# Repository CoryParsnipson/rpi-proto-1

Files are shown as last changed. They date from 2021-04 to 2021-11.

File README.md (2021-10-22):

# rpi-proto-1

This repository contains all (hw, fw, sw) resources for an RPI shell prototype.

# About

The models were made in FreeCAD 0.19. The Assembly4 addon was also installed.

```
OS: Windows 10 Version 2009
Word size of OS: 64-bit
Word size of FreeCAD: 64-bit
Version: 0.19.24276 (Git)
Build type: Release
Branch: releases/FreeCAD-0-19
Hash: a88db11e0a908f6e38f92bfc5187b13ebe470438
Python version: 3.8.6+
Qt version: 5.15.1
Coin version: 4.0.1
OCC version: 7.5.0
Locale: English/United States (en_US)
```

## Functional Blocks

### dpad\_test [Status: failure (do not use)]

This is a small test swatch for metal dome switch PCB trace. This also contains wire holders on the side which (for future reference) work really well for 22 AWG solid core wire.

### dpad\_tactile [Status: success (up to date)]

This is a 3 piece jig for holding OMRON B3F-1000 tactile switches into a dpad configuration. A 2015 new nintendo 3ds XL dpad and silicon mask go on top of the cover and underneath the dpad holder.

### abxy\_tactile [Status: success (up to date)]

This is a 3 piece jig for holding OMRON B3F-1000 tactile switches into an ABXY button cross configuration. This is sized specifically for a 2015+ new Nintendo 3DS XL dpad and silicon mask.

### thumbstick [Status: obsolete]

This is designed to hold a Nintendo Switch thumbstick and (breakout board)[https://www.amazon.com/gp/product/B0191ELDL0/ref=ppx\_yo\_dt\_b\_asin\_title\_o06\_s00?ie=UTF8&psc=1] together.

### thumbstick-v2 [Status: success (up to date)]

This is designed to hold a Nintendo Switch thumbstick and (breakout board)[https://www.amazon.com/gp/product/B0191ELDL0/ref=ppx\_yo\_dt\_b\_asin\_title\_o06\_s00?ie=UTF8&psc=1] together. This version uses two pieces to hold everything in place and requires printing the top piece with supports.

### shoulder-buttons-left-v1 [Status: obsolete]

This contains a 2 piece shoulder button holder along with 2 square shoulder buttons for the left side controller. This design is not very sturdy and it is overly complicated. Not recommended.

### shoulder-buttons-left-v2 [Status: success (up to date)]

This contains a 2 piece shoulder button holder along with 2 square shoulder buttons for the left side controller. This design is sturdier than v1. This does not fit the Nintendo 3DS shoulder buttons.

### controller-chassis-mount-left [Status: success (up to date)]

This is basically thumbstick-v2, dpad\_tactile, and shoulder-buttons-left-v2 fused together into one model. This will have attachments to be fitted onto a chassis and then put inside an outer enclosure. The L1 and L2 shoulder buttons should be printed with the ironing setting enabled for best effect. The select button holder in this is barely functional. This will be improved in the next version.

### controller-chassis-mount-right [Status: success (up to date)]

This is the right controller half, meant to hold a thumbstick, ABXY buttons, and shoulder buttons in place. This isn't a symmetric version of the left controller because the thumbstick only comes in one orientation so the breakout board is mounted vertically instead of horizontally like in the left side. This makes the right controller frame slightly wider than the left side.

### chassis-v1 [Status: obsolete]

This is the main parts to hold everything together. So far only consists of a part that screws into the screen and holds the two controller halves. This model can be used with no problems, but v2 is better.

### chassis-v2 [Status: success (up to date)]

This is a re-make with reinforced sides so the controller hooks bend less. The two protoboard holders has been changed to one protoboard holder and one USB Hub holder. This version also has speaker holders and screw holes for the front enclosure to screw into it.

### enclosure-v1 [Status: WIP]

Contains pieces for the outer case (henceforth referred to as the "enclosure"). Also contains models labeled "test-plate-\*" which are smaller pieces used to prototype fit and features (don't need to print these).

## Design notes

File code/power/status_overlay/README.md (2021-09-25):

Status Overlay
==============

This is a group of scripts that displays an overlay on the desktop with the 
current battery level and other status information (brightness, over-temp,
under/over voltage, etc). This overlay should be able to be hidden or shown
through external input and allow the user to select certain functions like
changing brightness or turning off the system.

Prerequisites
=============

These scripts use Python3. As of the time of this writing, both Python2
and Python3 are pre-installed on Raspbian, but to make Python3 the default,
there is a manual step that must be done.

```
 # manually switch from python2 to python3

 $ sudo rm /usr/bin/python
 $ sudo ln -s /usr/bin/python3 /usr/bin/python
```
 
Install python pip.

```
  $ sudo apt-get install python3-pip
```

Install RPI.GPIO.

```
  $ sudo apt-get install python3-rpi.gpio
```

Install pngview.

```
  $ git clone --depth 1 https://github.com/AndrewFromMelbourne/raspidmx.git
  $ cd raspidmx/
  $ make -j4
  $ sudo cp pngview/pngview /usr/local/bin/
```

Installation
============

```
  $ sudo make install # copy files to /usr/bin and install systemd service to run on boot
  $ sudo make clean   # undo everything that `make install` does

  $ sudo make status  # check on systemd service

  $ sudo make start   # manually start systemd service
  $ sudo make stop    # manually stop systemd service
```

References
==========

[1] https://sourceforge.net/p/raspberry-gpio-python/wiki/Home/ -  RPi.GPIO documentation and examples
[2] https://github.com/d-rez/gbz\_overlay - Reference for making an RPi graphical overlay
[3] https://github.com/torfsen/python-systemd-tutorial - Adding Python script as systemd service

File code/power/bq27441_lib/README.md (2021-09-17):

BQ17441 bash library
====================

This is a small set of functions to let you interface with the BQ27441 fuel
gauge through I2C.

Usage
-----

```
source bq27441 <i2c bus id> <fuel gauge i2c address>
```

e.g.)

```
  #> source bq27441 1 0x55
  #> get_battery_percentage
  #> 27
```

Prerequisites
-------------

```
  sudo apt-get install i2c-tools
  sudo apt-get install bc
```

Block Data Configuration
------------------------

Certain commands require you to put the device into a special "config update"
mode, unseal it, and configure block data access. This is all done with the
`enter_extended_mode` command. Use the corresponding `exit_extended_mode`
command to undo the special device access modes. This is important to
remember for writes especially because they do not get finalized back to
storage until the exit command is issued and the device has gone through
soft reset.

E.g.)

```
  source bq27441_lib.sh 1 0x55

  enter_extended_mode # will print to stderr and return non-zero status if fails
  
  read_block_data 0x52 0x0A 2
  # etc

  exit_extended_mode
```

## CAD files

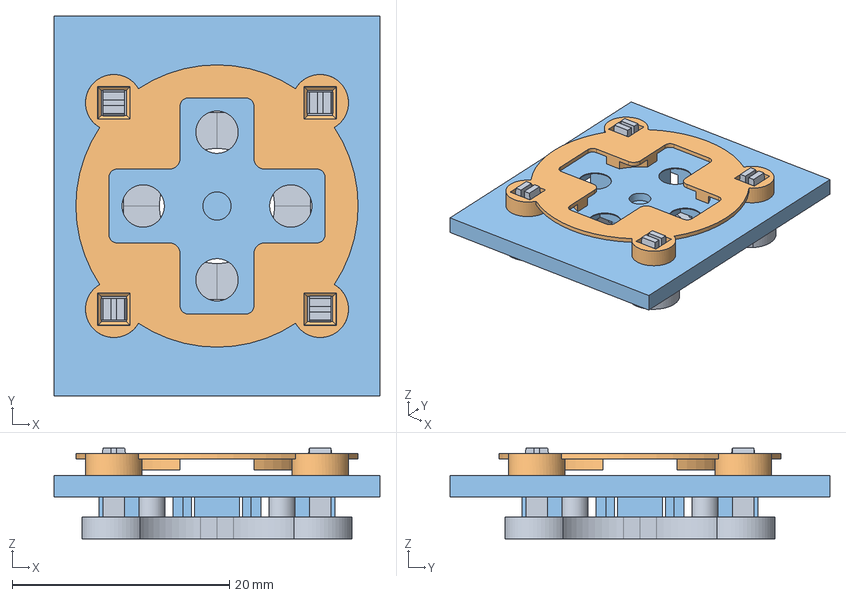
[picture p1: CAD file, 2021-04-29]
models/dpad_tactile/dpad_tactile_asm.FCStd
30.0 x 35.0 x 8.35 mm

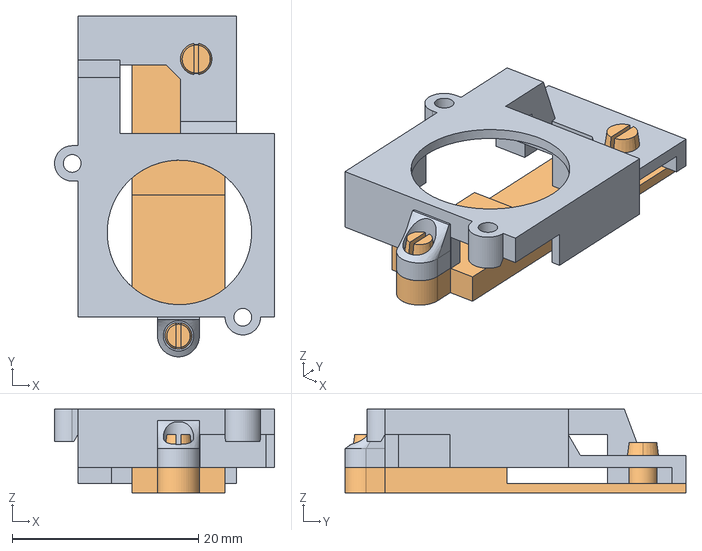
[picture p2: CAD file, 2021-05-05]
models/thumbstick-v2/thumbstick-asm.FCStd
23.6 x 36.5 x 9.00 mm

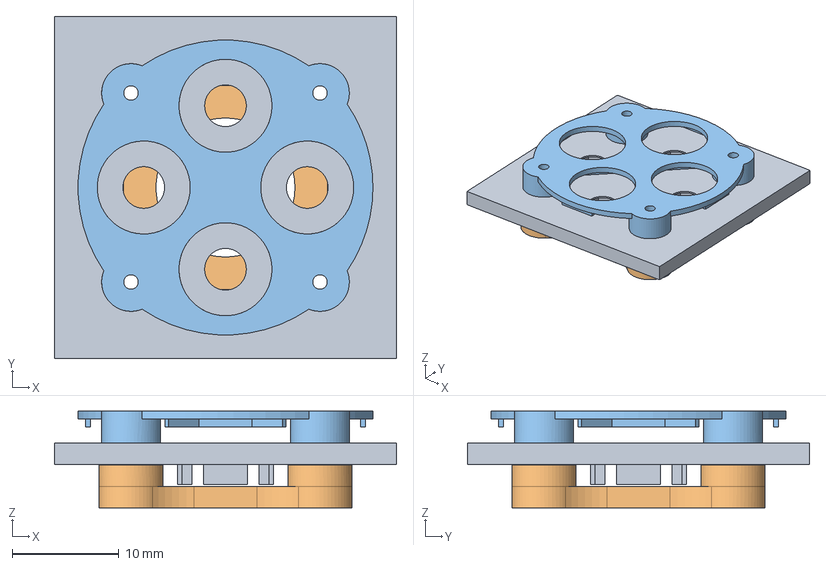
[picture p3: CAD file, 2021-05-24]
models/abxy_tactile/abxy-tactile-asm.FCStd
32.0 x 32.0 x 9.05 mm

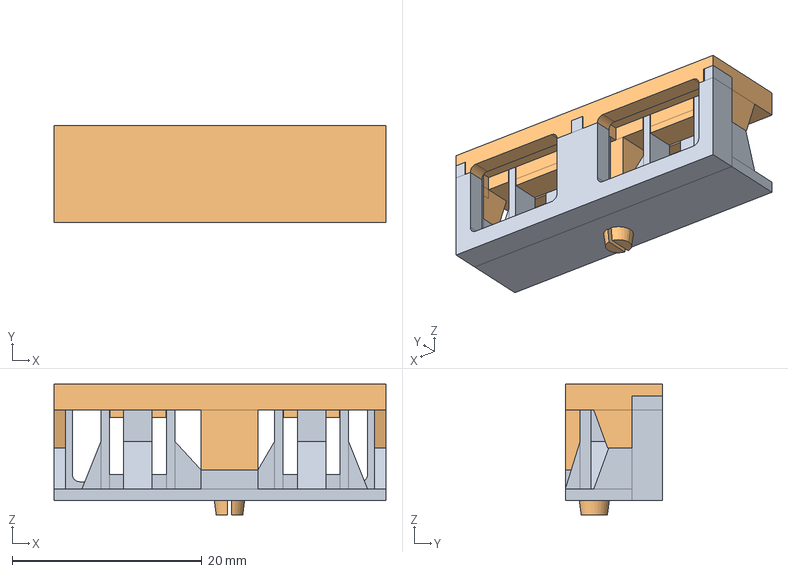
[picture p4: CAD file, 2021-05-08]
models/shoulder-buttons-left-v2/shoulder-buttons-asm.FCStd
35.0 x 10.2 x 13.8 mm

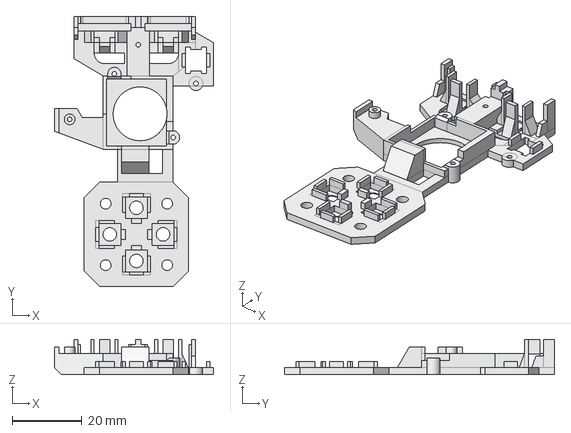
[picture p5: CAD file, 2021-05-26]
controller-chassis-mount-right/top-plate.FCStd
45.7 x 77.7 x 10.2 mm

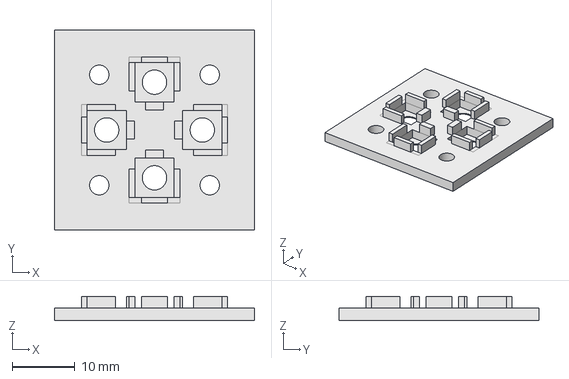
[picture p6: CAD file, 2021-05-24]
models/abxy_tactile/abxy-cover.FCStd
32.0 x 32.0 x 3.85 mm

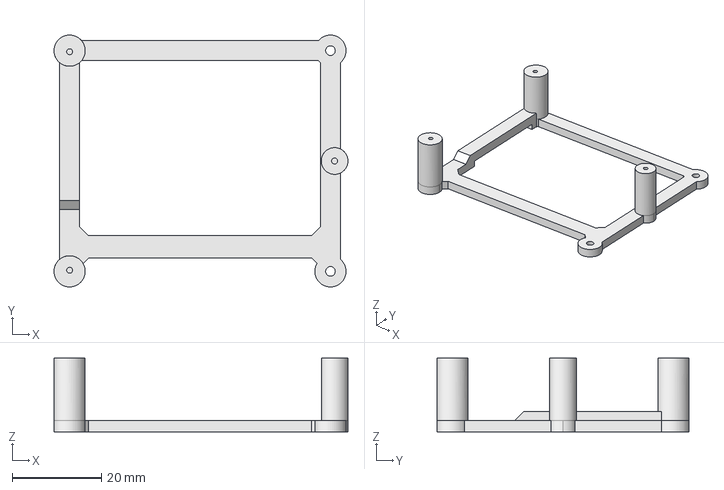
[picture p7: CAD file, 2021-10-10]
models/chassis-v2/rpi-mounting-bracket.FCStd
65.9 x 56.5 x 16.5 mm

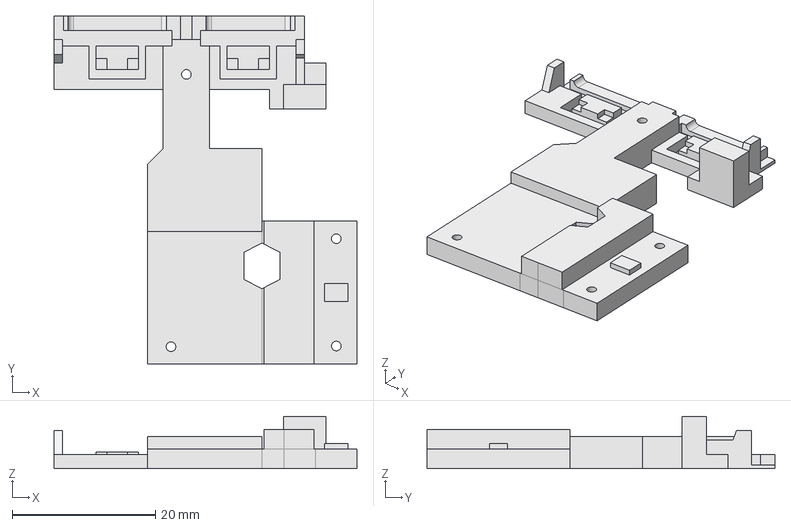
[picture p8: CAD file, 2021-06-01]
models/controller-chassis-mount-left/bottom-plate.FCStd
42.3 x 48.6 x 7.30 mm

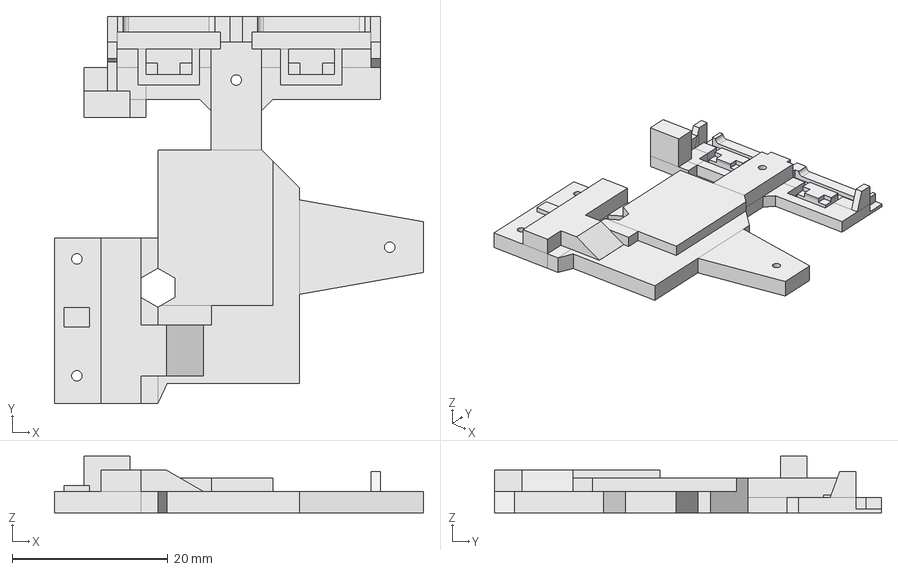
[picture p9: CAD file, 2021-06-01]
models/controller-chassis-mount-right/bottom-plate.FCStd
47.4 x 49.7 x 7.30 mm

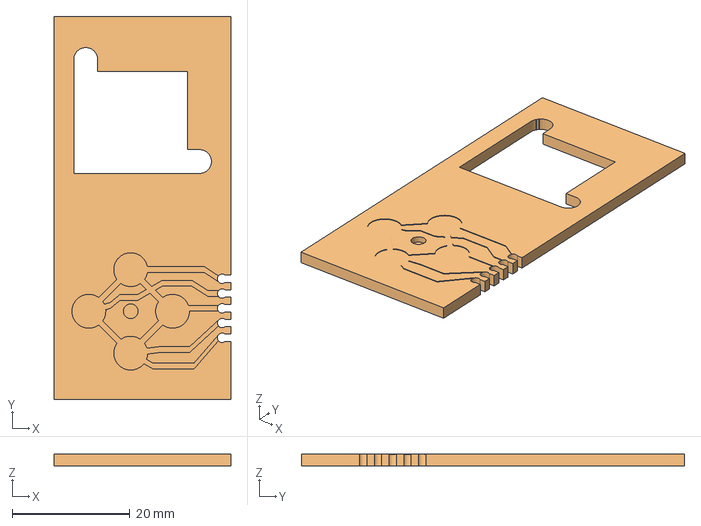
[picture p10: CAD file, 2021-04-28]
models/dpad_test/dpad_test.FCStd
30.0 x 65.0 x 2.00 mm
Pocket012 (Meshed)

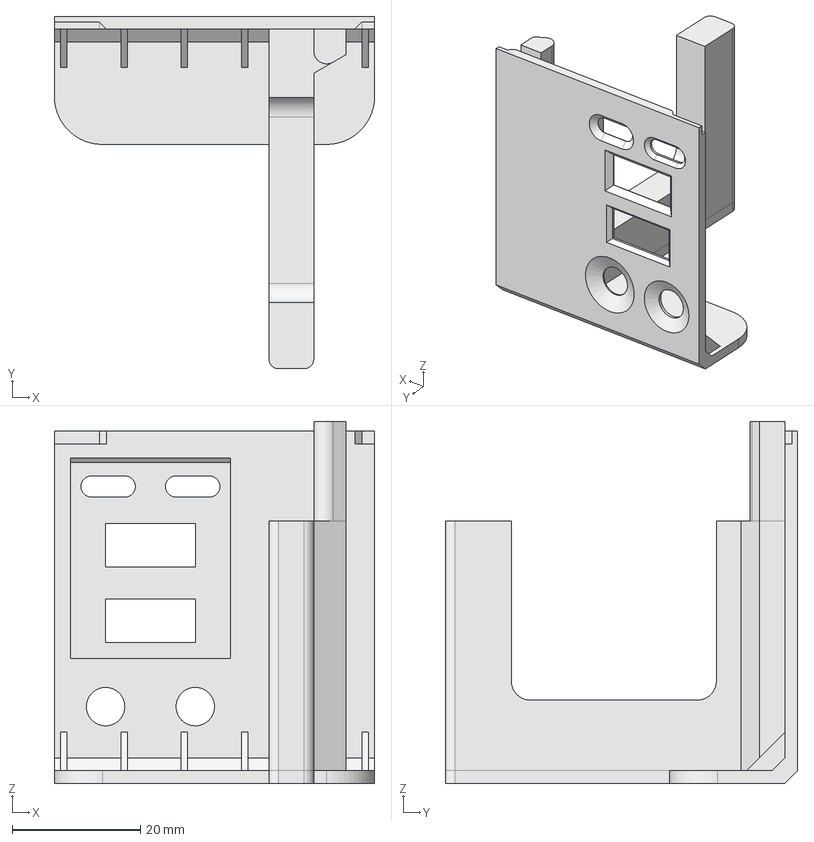
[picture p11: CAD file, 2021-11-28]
models/enclosure-v1/test-plate-chamfer-brace.FCStd
50.0 x 55.0 x 56.5 mm

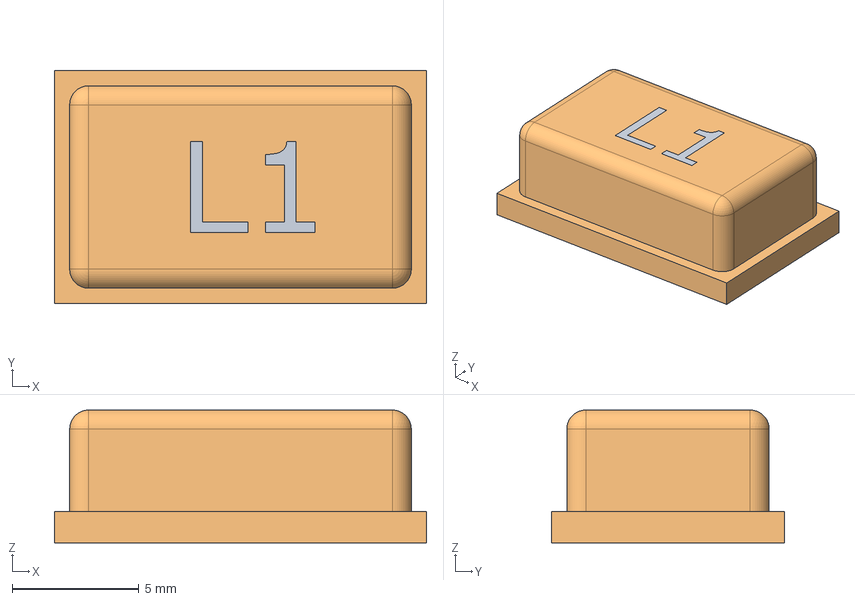
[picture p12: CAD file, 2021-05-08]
models/shoulder-buttons-left-v2/L1-button.FCStd
14.7 x 9.20 x 5.25 mm

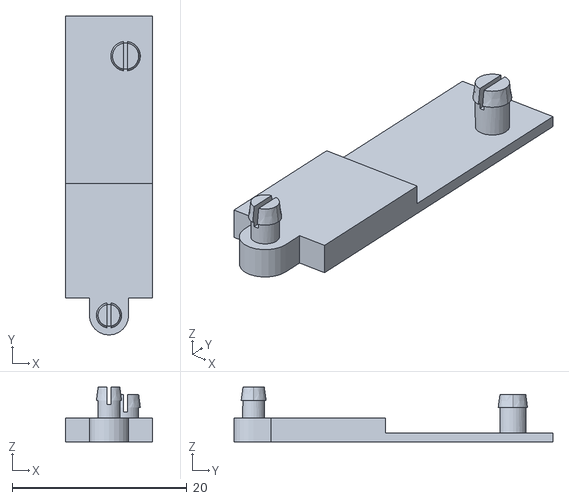
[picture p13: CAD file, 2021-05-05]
models/thumbstick-v2/thumbstick-holder-v2-bottom.stl
10.0 x 36.5 x 6.25

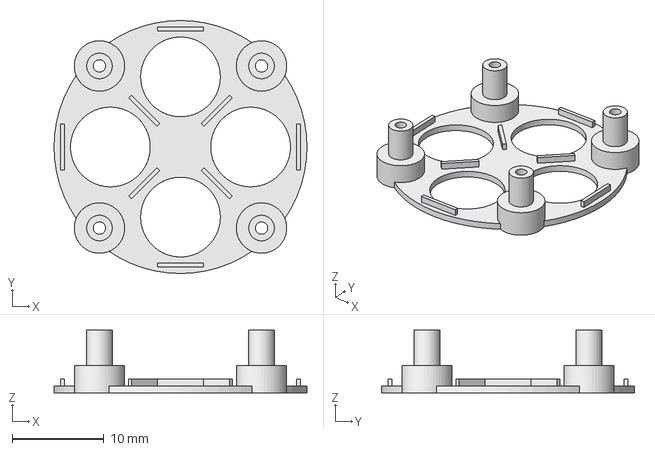
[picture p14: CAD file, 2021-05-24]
models/abxy_tactile/button-holder.FCStd
27.6 x 27.6 x 6.85 mm

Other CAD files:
models/chassis-v2/charger-mounting-bracket.FCStd
models/controller-chassis-mount-left/dpad_undercarriage.FCStd
models/controller-chassis-mount-right/prusa_mk3_settings.3mf
models/dpad_tactile/dpad_tactile_cover.FCStd
models/abxy_tactile/abxy-cover.stl
models/abxy_tactile/button-holder.stl
models/chassis-v1/screen-backing.FCStd
models/chassis-v1/screen-backing.stl
models/chassis-v2/charger-mounting-bracket.stl
models/chassis-v2/power-switch-holder.FCStd
models/chassis-v2/power-switch-holder.stl
models/chassis-v2/rpi-mounting-bracket.stl
models/chassis-v2/screen-backing.FCStd
models/chassis-v2/screen-backing.stl
models/chassis-v2/second-tier-holder-v2.FCStd
models/chassis-v2/second-tier-holder-v2.stl
models/chassis-v2/second-tier-holder.FCStd
models/chassis-v2/second-tier-holder.stl
models/controller-chassis-mount-left/L1-button.FCStd
models/controller-chassis-mount-left/L2-button.FCStd
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

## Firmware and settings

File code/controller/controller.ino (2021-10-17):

#include <HID-Project.h>
#include <HID-Settings.h>

#define MSG_LEN 80

#undef ENABLE_SERIAL // change to #define ENABLE_SERIAL if you want serial turned on

#ifdef ENABLE_SERIAL
  #define PRINT_SERIAL(...) \
    snprintf(msg, MSG_LEN - 1, __VA_ARGS__); /* snprintf to avoid accidental buffer overflow */ \
    Serial.println(msg);
#else
  #define PRINT_SERIAL(...) \
    do {} while(0)
#endif

#ifdef ENABLE_SERIAL
  #define INIT_SERIAL(baudRate) \
    Serial.begin(baudRate); \
    while (!Serial) { \
      ; /* wait for serial port to connect. Needed for native USB */ \
    } \
    PRINT_SERIAL("Serial monitor enabled")
#else
  #define INIT_SERIAL(baudRate) \
    do {} while(0)
#endif

const int refreshInterval = 1000;

char* msg = new char[MSG_LEN];

const int numRows = 4;
const int numCols = 4;

const int rowPins[numRows] = { 7, 8, 10, 16 };
const int colPins[numCols] = { 3, 4, 14, 15 };

const int leftThumbstickButtonPin = 9;
const int rightThumbstickButtonPin = 2;

// These calibrated values are different per individual thumbstick and need to be obtained
// by reading the value of the analog pins, bringing the thumbstick to the max/min of each axis
// and then using a number that is ~10 smaller/larger than what is observed.
const int rXMinCalibrated = 85;
const int rXMaxCalibrated = 850;
const int rYMinCalibrated = 160;
const int rYMaxCalibrated = 840;

const int lXMinCalibrated = 170;
const int lXMaxCalibrated = 890;
const int lYMinCalibrated = 100;
const int lYMaxCalibrated = 840;

const int pinLXAxis = A0;
const int pinLYAxis = A1;
const int pinRXAxis = A3;
const int pinRYAxis = A2;

void reset();
inline void printAnalog(const int16_t xval, const int16_t yval);
int16_t readAxis(int pin, const int min, const int max, boolean returnRaw = false);

void setup() {
  digitalWrite(pinLXAxis, LOW);
  digitalWrite(pinLYAxis, LOW);
  digitalWrite(pinRXAxis, LOW);
  digitalWrite(pinRYAxis, LOW);

  // thumbstick buttons are not part of key matrix
  pinMode(leftThumbstickButtonPin, INPUT_PULLUP);
  pinMode(rightThumbstickButtonPin, INPUT_PULLUP);
    
  reset();

  INIT_SERIAL(115200);

  Gamepad.begin();
}

void loop() {
  static unsigned long now = 0, nextUpdate = 0;
  now = micros();

  if (nextUpdate < now) {
    // TODO: maybe sleep would let us squeeze out extra battery life here
    nextUpdate = now + refreshInterval; 

    for (int c = 0; c < numCols; ++c) {
      byte col = colPins[c];
      pinMode(col, OUTPUT);
      digitalWrite(col, LOW);
  
      for (int r = 0; r < numRows; ++r) {
        byte row = rowPins[r];
        byte current_button = c * numCols + r + 1;

        pinMode(row, INPUT_PULLUP);
        bool button_state = !digitalRead(row);
        pinMode(row, INPUT); // set pin to hi-z
  
        if (button_state) {
          Gamepad.press(current_button);
          PRINT_SERIAL("Row %i, Col %i detected", row, col);
        } else {
          Gamepad.release(current_button);
        }
      }
      pinMode(col, INPUT);
    }

    // left thumbstick button polling
    if (!digitalRead(leftThumbstickButtonPin)) {
      Gamepad.press(numRows * numCols + 1);
    } else {
      Gamepad.release(numRows * numCols + 1);
    }

    // right thumbstick button polling
    if (!digitalRead(rightThumbstickButtonPin)) {
      Gamepad.press(numRows * numCols + 2);
    } else {
      Gamepad.release(numRows * numCols + 2);
    } 

    Gamepad.xAxis(readAxis(pinLXAxis, lXMinCalibrated, lXMaxCalibrated));
    Gamepad.yAxis(-1 * readAxis(pinLYAxis, lYMinCalibrated, lYMaxCalibrated)); // invert y axis
    
    Gamepad.rxAxis(readAxis(pinRXAxis, rXMinCalibrated, rXMaxCalibrated));
    Gamepad.ryAxis(-1 * readAxis(pinRYAxis, rYMinCalibrated, rYMaxCalibrated)); // invert y axis

    Gamepad.write();
  }
}

void reset() {
  for (int r = 0; r < numRows; ++r) {
    pinMode(rowPins[r], INPUT);
  }
  
  for (int c = 0; c < numCols; ++c) {
    pinMode(colPins[c], INPUT_PULLUP);
  }
}

void printAnalog(int16_t xval, int16_t yval) {
  PRINT_SERIAL("x-axis: %d, y-axis: %d", xval, yval);
}

int16_t readAxis(int pin, const int min, const int max, bool returnRaw) {
  uint16_t read = analogRead(pin);
  if (returnRaw) {
    return read;
  }

  return map(constrain(read, min, max), min, max, -32767, 32767);
}

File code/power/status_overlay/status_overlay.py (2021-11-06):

#!/usr/bin/env python3

import datetime
import imghdr
import json
import os
import re
import signal
import struct
import subprocess
import sys
import threading
import time

import RPi.GPIO as GPIO


CONFIG = {}

CONFIG["CONFIG_FILE_PATH"] = "~/.status_overlay_config"

CONFIG["IMAGE_PATH"] = "images/"
CONFIG["SOUND_PATH"] = "sounds/"
CONFIG["LIB_PATH"] = "lib/"
CONFIG["PNGVIEW_PATH"] = "pngview"
CONFIG["SCREENSHOT_PATH"] = "~/screenshots"

CONFIG["LAYER_DEFAULT"] = 15000
CONFIG["LAYER_BATTERY"] = CONFIG["LAYER_DEFAULT"] + 5
CONFIG["LAYER_NUMBER"] = CONFIG["LAYER_DEFAULT"] + 10
CONFIG["LAYER_BACKDROP"] = CONFIG["LAYER_DEFAULT"] - 10
CONFIG["LAYER_NOTIFICATION"] = CONFIG["LAYER_DEFAULT"] + 15

CONFIG["DISPLAY_ID"] = 0
CONFIG["IS_VISIBLE"] = True

# INITIAL_ON -> toggle mode, start with hud visible
# INITIAL_OFF -> toggle mode, start with hud hidden
# SAVED -> toggle mode, start with state read from config file
# FLASH (show hud on button press for a short time then hide)
# FLASH_INITIAL_ON -> Flash mode with hud shown for 3 seconds on start
CONFIG["POWER_SWITCH_BEHAVIOR"] = "SAVED"

CONFIG["POWER_SWITCH_FLASH_DURATION"] = 3 # in seconds

CONFIG["FUEL_GAUGE_SCRIPT_PATH"] = CONFIG["LIB_PATH"] + "bq27441_lib/"
CONFIG["FUEL_GAUGE_I2C_BUS_ID"] = 1
CONFIG["FUEL_GAUGE_I2C_DEVICE_ID"] = 0x55

CONFIG["BATTERY_GPOUT_PIN"] = 29 # board pin 29 is GPIO5
CONFIG["BATTERY_POWER_PIN"] = 36 # board pin 36 is GPIO16 (tied to GPIO6 in hardware)

CONFIG["LOW_BATTERY_NOTIFICATION_DURATION"] = 5 # in seconds
CONFIG["CRITICAL_BATTERY_NOTIFICATION_DURATION"] = 10 # in seconds
CONFIG["LOW_BATTERY_THRESHOLD"] = 10
CONFIG["CRITICAL_BATTERY_THRESHOLD"] = 5


__ORIGINAL_SIGINT__ = None
__LAST_POWER_BUTTON_PRESSED_TIME__ = None
__PNGVIEW_PROCESSES__ = {}
__NOTIFICATION_PROCESSES__ = {}
__DIMENSION_CACHE__ = {}
__PREVIOUS_STATE_OF_CHARGE__ = 100
__SHUTDOWN_LOCK__ = threading.Lock()
__SCRIPT_PATH__ = os.path.dirname(os.path.realpath(__file__))


# -----------------------------------------------------------------------------
# Configuration utilities
# -----------------------------------------------------------------------------
def read_config_file(config_file_path):
    """ Read the config file, if it exists and update the necessary
        configuration parameters and return a dictionary with the
        configuration parameters.

        NOTE: this does not overwrite the configuration, the caller
        must do this themselves.
    """
    config_file_path = os.path.expanduser(config_file_path)
    config = CONFIG

    try:
        with open(config_file_path, 'r') as fhandle:
            serialized = ' '.join(fhandle.readlines())
            config = json.loads(serialized)
    except FileNotFoundError as e:
        print("WARNING: Could not find config file at '%s'. Using default config." % config_file_path)
        write_config_file(config_file_path)

    if config["POWER_SWITCH_BEHAVIOR"] == "INITIAL_OFF":
        config["IS_VISIBLE"] = False
    elif config["POWER_SWITCH_BEHAVIOR"] == "INITIAL_ON":
        config["IS_VISIBLE"] = True
    elif config["POWER_SWITCH_BEHAVIOR"] == "FLASH" or config["POWER_SWITCH_BEHAVIOR"] == "FLASH_INITIAL_ON":
        config["IS_VISIBLE"] = False

    return config


def write_config_file(config_file_path, write_args=CONFIG.keys()):
    """ Write the config file, writing it if it does not exist

        Caller can provide an optional list of CONFIG keys. If this
        list is not empty, only the values in the keys will be
        updated. The other values will be read from the current
        state of the config file.
    """
    config_file_path = os.path.expanduser(config_file_path)
    config = {}
    try:
        with open(config_file_path, 'r') as fhandle:
            serialized = ' '.join(fhandle.readlines())
            config = json.loads(serialized)

            for k in write_args:
                config[k] = CONFIG[k]
    except FileNotFoundError as e:
        config = CONFIG

    try:
        with open(config_file_path, 'w+') as fhandle:
            serialized = json.dumps(config, indent=2, sort_keys=True)
            fhandle.write(serialized)
    except Exception as e:
        print("Error opening config file: %s" % config_file_path)
        print(e)
        sys.exit(1)


# -----------------------------------------------------------------------------
# Graphical utilites
# -----------------------------------------------------------------------------
def pngview(draw_id, pngfile, dont_save_pid=False, **kwargs):
    """ Call pngview to display an image on the screen. Returns a process id
        that the pngview call is running in.

        NOTE: it is important to properly set draw_id. This is a unique (string)
        identifier that should specify which sprite we are drawing. This is
        important because when we want to update or animation sprites, we must
        kill the previous pngview call of the sprite and then make a new one.
        Failing to keep track of draw_id properly may cause duplicates to
        appear on the script after updates and also cause memory leaks as more
        and more pngview calls add up (leading to screen de-sync).
        
        Use kwargs to set pngview parameters:

        -b - set background colour 16 bit RGBA
              e.g. 0x000F is opaque black
        -d - Raspberry Pi display number
        -l - DispmanX layer number
        -x - offset (pixels from the left)
        -y - offset (pixels from the top)
        -t - timeout in ms
        -n - non-interactive mode
    """
    if 'b' not in kwargs:
        kwargs['b'] = 0

    if 'n' not in kwargs:
        kwargs['n'] = ""

    pngview_call = [val for pair in zip(
        ["-" + str(k) for k in kwargs.keys()],
        [None if not str(v) else str(v) for v in kwargs.values()]
    ) for val in pair]

    pngview_call.insert(0, CONFIG["PNGVIEW_PATH"])
    pngview_call.append(pngfile)

    pngview_call = filter((None).__ne__, pngview_call)

    pid = subprocess.Popen(pngview_call)
    time.sleep(0.025) # this is a hack to prevent flickering
    if draw_id in __PNGVIEW_PROCESSES__:
        __PNGVIEW_PROCESSES__[draw_id].kill()

    if not dont_save_pid:
        __PNGVIEW_PROCESSES__[draw_id] = pid

    return pid


def screen_resolution(display_id=0):
    """ Returns a pair of integers with the screen resolution of the specified
        display. The first coordinate is 'x' (screen width) and the second is
        'y' (screen height).
    """
    results = subprocess.run(["tvservice", "-s", "-v", str(display_id)], capture_output=True)
    resolution = re.search("(\d{2,}x\d{2,})", results.stdout.decode('utf-8'))

    if not resolution or results.returncode != 0:
        raise ChildProcessError("screen_resolution failed: %s" % results.stderr.decode('utf-8'))

    return [int(x) for x in resolution[0].split("x")]
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

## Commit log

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2021-04-28 Resize dpad holder hole and use square snap ins.
    Add sides to the dpad cover switch holes.
    [dpad_tactile_asm.FCStd, dpad_tactile_cover.FCStd, dpad_tactile_cover.stl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]
2021-04-29 Move fastener pegs farther out and make smaller.
    Make the pegs 2x2mm instead of 3x3mm to make them more flexible. Reduce
    peg width to jut out 0.2mm instead of 0.3mm. Make the pegs 1mm tall
    instead of 2mm tall. Move the pegs out to 9.5mm to make more room for
    the silicon membrane to flatten out.
    [dpad_tactile_asm.FCStd, dpad_tactile_cover.FCStd, dpad_tactile_cover.stl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]
2021-04-29 Change webbing radius on dpad holder.
    Make the webbing slightly wider in radius because it was rubbing against
    the plastic dpad cover and making scratching noises. This size fits
    much, much better.
    [dpad_tactile_asm.FCStd, dpad_tactile_dpad_holder.FCStd, dpad_tactile_dpad_holder.stl]
2021-04-29 Widen switch holes in cover for more leeway.
    This is the bottom layer so may be subject to expansion from elephant
    foot effect when 3d printing it. If the hole is too small, it will
    prevent the switch pad from extending through the hole. This is bad
    because the switch will always be closed.
    [dpad_tactile_asm.FCStd, dpad_tactile_cover.FCStd, dpad_tactile_cover.stl]
2021-05-02 Add holder for thumbstick and breakout board.
    Still very much WIP. Adding dowel pads to hold the thumbstick in place,
    but these should be replaced by holes to fit M1.6 0.35" screws.
    [thumbstick-breakout-holder.stl, thumbstick-breakout.FCStd]
2021-05-03 Add thumbstick top holder piece and corrections.
    Add a top holder that goes over the thumbstick and connects to the
    bottom piece through the dowels.
    There might be a better way to do this...
    [thumbstick-asm.FCStd, thumbstick-breakout-holder.stl, thumbstick-breakout.FCStd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]
2021-05-04 Add thumbstick v2 design.
    Flip the orientation of the model to put the mass into the top piece
    instead. This requires using supports and some pegs to connect to the
    bottom piece. Connecting this to the dpad and other pieces will allow us
    to remove the need for supports. Pegs should be replaced with screwholes
    and screws.
    [thumbstick-asm.FCStd, thumbstick-holder-bottom.FCStd, thumbstick-holder-v2-bottom.stl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]
2021-05-05 Adjust thumbstick-v2 bottom part.
    Make the mounting board peg 0.5mm shorter and correct the base pad and
    breakout board holding notch to be the proper sizes.
    [thumbstick-asm.FCStd, thumbstick-holder-bottom.FCStd, thumbstick-holder-v2-bottom.stl]
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2021-05-10 Add controller chassis mount model. Still WIP.
    Finished top-plate design to fuse thumbstick holder and tactile dpad top
    pieces together. Need to add in holder for select button and figure out
    how to couple this piece to the shoulder buttons.
    [top-plate.FCStd]
2021-05-11 Add shoulder buttons top piece.
    Still need to figure out fastening features and to add the select button
    hole. FreeCAD is starting to crap out on me.
    [top-plate.FCStd]
2021-05-12 Add select button holder to the left controller.
    Add select button holder to the left controller top plate. This switch
    needs to stick out above the top surface by a little bit so the button
    goes past the enclosure.
    [top-plate.FCStd]
2021-05-12 Add upper and lower screw holes to left controller.
    Add screw holes to the top plate. This is assuming that the screws are
    going in from the bottom plate.
    [top-plate.FCStd]
2021-05-12 Add dpad holder with new legs. Adjust screw holes.
    Change dpad holder from dpad_tactile design to be 1mm thick instead of
    0.5mm for added strength. Change peg holes to legs with screw holes.
    Change screw holes in the top plate model to be 0.675mm in diameter
    instead of 0.95. (The old size was incorrect for M1.6 screws)
    [dpad_holder.FCStd, top-plate.FCStd]
2021-05-13 Add assembly and change select button in top plate.
    Remove bottom plate to the select button holder in the top plate because
    this will trap the switch when the wires are soldered. Instead make the
    side pads longer and have them slot into the bottom plate.
    Also add a screw hole near the select button switch to secure the select
    button holder (to be made later).
    [dpad_holder.FCStd]
2021-05-13 Add bottom plate to left controller.
    Complete the left controller frame assembly. The only thing missing now
    is a little plate to hold the top of the select button in place.
    NOTE to self: I've been thinking for a couple days that the extra
    difficulty of creating a separate inner frame outweight the benefits of
    having it when there aren't PCB's inside to hold everything in place. It
    would probably be much stronger and easier to merge the top-plate into
    the front face of the enclosure, separate the middle section that holds
    the top of the dpad switches in place as its own piece, and separate the
    shoulder button bottom section as its own piece.
    [bottom-plate.FCStd, dpad_holder.FCStd]
2021-05-14 Create meshes for finalized left controller frame.
    Still missing select button holder. Add meshes to repo.
    [bottom-plate.FCStd, bottom-plate.stl, dpad-holder.stl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]
2021-05-14 Shrink dpad holder fastener columns slightly.
    With 0.5mm clearance in the radius of the dpad holder fastener columns
    and the top and bottom plate holes, it's really hard to get them to fit
    together. Change dpad holder columns from 1.45mm to 1.4mm radius for
    better fit.
    [dpad-holder.stl, dpad_holder.FCStd]
2021-05-15 Add shoulder buttons and select button.
    Copy and paste the L1 and L2 buttons from the shoulder buttons model and
    increase their height by 1mm to account for the distance that will be
    covered by the outer enclosure thickness. NOTE: print out these buttons
    using ironing enabled in the 3d printer settings.
    Add first draft of the select button holder. NOTE: this doesn't work in
    its current form.
    [L1-button.FCStd, L2-button.FCStd, l1-button.stl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]
2021-05-15 Tweak left controller holder parts.
    Increase the column height of the dpad holder fastener columns to 3.25mm
    (+0.75mm) to allow for the dpad plastic cover to jiggle around more when
    you press the buttons. This extra leeway feels much, much better.
    Increase the column height of the select button holder by 1mm to 3mm
    tall to allow for proper clearance of the squishy silicon membrane and
    button. This is too high, but still works. Widen the button hole from
    2.5mm radius to 2.6mm radius.
    NOTE: the select button holder is flexible like paper and really shitty,
    but it works for now. It's going to be revised out in the next iteration
    anyway.
    [dpad-holder.stl, dpad_holder.FCStd, select-button-holder.FCStd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]
2021-05-19 Add initial portion of the chassis.
    This part contains screw holes and fastening surfaces for nuts on the
    back of the screen and for screwing a protoboard in place. There is also
    a hook jutting out for the left controller to fasten on to.
    The printed result is pretty sturdy but has slight flex over all of the
    part. The screen holes for nut fastening are a good thickness and size
    to allow for the screws to go through them. They are all aligned. The
    fastener columns for the right protoboard are in the right spot too. Reinforcements around the left controller hook might be necessary.
    Overall, it looks really cool.
    Need to add 3 fastener columns for the left protoboard as well as a hook
    for th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
    [screen-backing.FCStd, screen-backing.stl]
2021-05-19 Make bottom plate changes on left controller frame.
    Enlarge the dpad holder openings because even with 0.1mm clearance they
    still got stuck. This is bad because when you go to remove the parts
    from each other, the dpad holder legs can break off.
    Change the shape of the chassis hook to be just a square. Need more
    material around the screw holes.
    [bottom-plate.FCStd, bottom-plate.stl]
2021-05-20 Fill out screen backing part.
    Add right controller hook and left protoboard fastening features.
    [screen-backing.FCStd, screen-backing.stl]
2021-05-24 Beef up left controller hook in screen backing.
    Add stronger reinforcement to prevent frame flexing. This works
    moderately well. The left controller still flexes, but feels more
    sturdy.
    [screen-backing.FCStd]
2021-05-24 Add ABXY jig.
    This was surprisingly hard. It took a bit of iterating to find the right
    spacing for the button holes and button-holder walls to hold the buttons
    in place without having them spin around.
    The vertical clearance of the button-holder and abxy-undercarriage was
    also modified w.r.t. the dpad jig as well. The button holder top surface
    is only 0.75mm thick vs 1mm thick of the dpad button holder. The columns
    of both are 3mm total. The undercarriage of the abxy jig is not 1.85mm
    like the dpad undercarriage, but has been expanded to be 2mm to allow
    clearance for the things that jut out from underneath the tactile
    switches. I suspect that the dpad undercarriage would actually benefit
    fr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
    [abxy-cover.FCStd, abxy-cover.stl, abxy-tactile-asm.FCStd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]
2021-05-26 Add right controller frame without bottom plate.
    Add top plate for right controller. The breakout board had to be rotated
    counter-clockwise by 90 degrees to get it to fit. This messed up the
    thumbstick portion of the plate and also makes it slightly wider than
    the left controller frame...
    [R1-button.FCStd, R1-button.stl, R2-button.FCStd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]
2021-05-27 Add WIP right controller bottom plate and asm.
    The right controller plate is still WIP. Needs corrections on the PCB
    holder arm and shoulder buttons. They are slightly misaligned. Saving
    this intermediate step in case I change something and break it
    irrevocably. You know how it is.
    [bottom-plate.FCStd, bottom-plate.stl]
2021-05-27 Fix right controller bottom plate alignment.
    Fixed the alignment issues in the previous commit that were mentioned
    about the right controller frame bottom plate. More specifically, the
    breakout board bottom holder pad was moved 1mm to the left (the
    guideline was incorrect) and the fastening hole was adjusted too. The
    bottom holder pad was reduced in height by 1mm and moved upwards to
    compensate. The shoulder buttons was also moved 1mm to the left due to
    the same mistake as the previous change.
    [bottom-plate.FCStd, bottom-plate.stl]
2021-05-28 Fix right controller top/bottom plates.
    Fixes to the right controller frame made after printing them out.
    The top frame had the thumbstick wall cutouts too shallow. Changed these
    to the right height. Also moved the thumbstick screw pads slightly to
    make them fit better. This was not done to the original feature, but by
    pocketing the old ones and then padding new ones in their place to avoid
    breaking all the steps that happened after.
    The bottom frame needed the thumbstick extrusion to be .75mm thinner on
    the right and added a small reinforcement pad on the left. Decrease the
    height of the undercarriage body by 0.15 to compensate from the columns
    being 2mm instead of 1.85mm.
    Add the prusa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
    [bottom-plate.FCStd, bottom-plate.stl, prusa_mk3_settings.3mf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]
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2021-05-31 Move Freecad models into models folder. Add code.
    Add a code folder for arduino key matrix code.
    [L1-button.FCStd, L2-button.FCStd, R1-button.FCStd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]
2021-06-01 Separate controller bottom plates.
    Need to separate dpad and ABXY undercarriages from the rest of the
    bottom plates to make it easier to wire up the switches. The button
    cross switch wiring is probably going to be the most difficult part of
    putting the controller together.
    [abxy-undercarriage.FCStd, abxy-undercarriage.stl, bottom-plate.FCStd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]
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2021-06-09 Add WIP of screen-backing version 2.
    Simplify the shapes and history tree of the screen-backing model. The
    version 2 will have speaker holders, and changed from 2 protoboard
    holders side by side to 1 protoboard holder on the right and a USB hub
    holder on the right. The plan is to stack the two protoboards on top of
    each other instead of side by side.
    In this commit, the base shape is created. The features on the
    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
    [screen-backing.FCStd]
2021-06-09 Add controller hooks and screw holes to chassis v2.
    Add all features to bring up to parity with chassis v1. Need to add
    speaker holders and USB hub holder.
    [screen-backing.FCStd]
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2021-09-20 Add pigpio test.
    Using pigpio will let me avoid using a second GPIO pin for monitoring
    the power switch at the expense of constant 6% CPU usage.
    [status_overlay.py]
2021-09-22 Clean up README and remove test scripts.
    Don't need test scripts anymore, get rid of them for clarity. You can
    still refer to them in the git history.
    Correct readme. Don't need to install GTK and PyGObject anymore. Need
    pngview instead.
    [status_overlay.py]
2021-09-23 Update number pngs. Add draw code.
    NOTE: this contains a commented out test that will countdown all
    numbers and wrap around back to the top at zero. Will toggle between
    charging and discharging states on underflow.
    Need to figure out two problems:
    1. Upon draw update, the hud flashes. Need to figure out if there's some
    kind of double buffering we can do.
    2. When I press Ctrl^C to end the script, this leaves the terminal in
    a bad state and I need to reboot to fix everything.
    [status_overlay.py]
2021-09-23 Flicker hack.
    Use value of 25 millisecond sleep through trial and error to remove
    flicker. Pngview doesn't seem designed to animate or provide
    constant refreshes, so a real fix would be to use the dispmanx API
    directly, but that's too much effort for now.
    [status_overlay.py]
2021-09-24 Default values so overlay doesn't cover emulators
    Add default values for -b and -n flags so the overlay doesn't cover
    emulators.
    [status_overlay.py]
2021-09-24 Bug fixes, add charging query, and hook up bq lib.
    Fix memory leak related to the LCD display "de-syncing" or fogging
    up when the script was exited. This happened because the
    PNGVIEW_PROCESSES were not killed cleanly causing something to
    crash. Cleaning up PNGVIEW_PROCESSES in on_exit() seems to fix
    this.
    Add bq27441 lib function to check the flags to see if the device
    is discharging. Use the boolean negation of this function to see
    if the device is charging.
    Bug fix related to the above where the charging variable was not
    correctly routed through draw_hud() and the battery image drawing
    function.
    Hook up the bq27441 lib function call to the display code logic
    through the SOC interrupt.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
    [status_overlay.py]
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2021-09-25 Add Makefile and Systemd configuration.
    Add a Makefile that lets you install and uninstall this script as
    a systemd service.
    Numerous bugfixes related to getting the above working.
    [status_overlay.py]
2021-09-25 Fix comment typo in status_overlay code.
    [status_overlay.py]
2021-09-26 Fix read/write config bug. Add notification funcs.
    [status_overlay.py]
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2021-10-05 Add second tier holder v2 and associated parts.
    Need to cut out pin clearance holes on power supply component holders.
    Also still need to make RPi holding bracket.
    [charger-mounting-bracket.FCStd, charger-mounting-bracket.stl, power-switch-holder.FCStd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]
2021-10-06 Changes made to second tier holder in chassis-v2
    Thicken the USB Holder Wall to match the first version. This was
    accidentally made too thin in the second version. This necessitated
    moving the audio wires hole a little bit to the side. This should
    have no impact on the alignment of other parts.
    Remove one screw hole under the power switch footprint and add a
    pin clearance cutout hole instead.
    Add a pin clearance cutout hole to the 5V regulator footprint.
    [second-tier-holder-v2.stl]
2021-10-10 Create RPi mounting bracket and add to chassis asm
    [rpi-mounting-bracket.FCStd, rpi-mounting-bracket.stl]
2021-10-13 Changes to second tier holder v2 in chassis-v2.
    Remove USB cable press. Instead create a pocket to give the cable
    extra clearance.
    Also fix many other issues:
    Widen the screw access holes in the controller button pads so that
    the 1.6M screws with a 1mm tall head can fit in it.
    Center the power switch holder screw holes in the middle of the pad.
    [second-tier-holder-v2.stl]
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2021-10-17 Style unification.
    Remove indent characters and replace with spacing. Fix indentation.
    Change snake case to camelcase to match Arduino standard.
    Add cuddling parentheses to places that need it.
    Shorten readAxis() body.
    [controller.ino]
2021-10-17 Style unification.
    Fix capitalization on const int variables and convert to camel case.
    [controller.ino]
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2021-10-22 Create test plate for left controller cover. WIP
    Stop at creating a chamfer or fillet on the edge of the enclosure test
    plate. (I want to test what fillet looks like on a bed facing surface
    that will be 3d printed. Also going to make a chamfered version to
    compare.)
    Still need to create:
    * a panel line for the LCD screen
    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
    [test-plate-left-controller.FCStd]
2021-10-22 Add screen panel line to left controller testplate
    [test-plate-left-controller.FCStd]
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2021-10-22 Add cut out select button text in enclosure test
    [test-plate-left-controller.FCStd]
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2021-11-01 Fix typo in last commit...
    [status_overlay.py]
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2021-11-05 Bugfix for status overlay screenshot.
    Change from 12 hour clock to 24 hour clock so the snapshots remain in
    better lexographical order. Also add seconds to the timestamp to fix bug
    where if you took too multiple screenshots within a minute, subsequent
    pictures would overwrite the previous ones.
    [status_overlay.py]
2021-11-06 START and ABXY cutout adjustments in front cover
    Increase height of cutout spaces for both the ABXY button cross and the
    Start button.
    [front-cover.FCStd, front-cover.stl]
2021-11-08 Fix bottom screw holes on front-plate enclosure.
    Man, FUCK FreeCAD.
    [front-cover.FCStd, front-cover.stl]
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2021-11-21 Create test plate for connector holes.
    Charging port hole is 0.9mm too high. The power button hole is 0.5mm too
    high. The USB ports need to be increased in height by 0.5mm and shifted
    to the left by 0.3mm.
    [test-plate-connectors.FCStd, test-plate-connectors.stl]
2021-11-22 Create back-cover. Still WIP
    The back cover needs more connector holes and supports in the middle.
    [back-cover.FCStd]
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
